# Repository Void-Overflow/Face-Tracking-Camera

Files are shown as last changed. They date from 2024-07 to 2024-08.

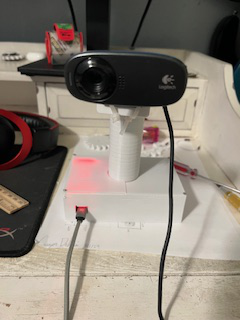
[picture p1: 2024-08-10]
Demo Images and Video/IMG_9484.jpg

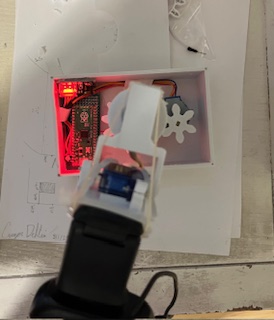
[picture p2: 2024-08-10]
Demo Images and Video/IMG_9477.jpg

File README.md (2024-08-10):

# Face-Tracking-Camera
An RP2040 based mechanical facial tracker with a C++ interface utilizing OpenCV to physically track faces detected in the user's webcam using stepper and servo motors.

Description: 

This project uses the Rasperry Pi Pico microcontroller to run Arduino code which uses UART to communicate with my C++ program. It receives the determined coordinates of a detected face in the webcam with the center of the camera as the origin. It then maps the values from those coordinates to a stepper motor to move it horizontally and a servo to vertically move the camera. The webcam should be mounted on top of the 3d printed base. A slip ring should be used to prevent the wires above the stepper from being tangled. The C++ interface was written in Visual Studio, and it uses OpenCV to detect and track faces from a pretrained haarcascade file. It additionally uses the Windows.h library to communicate with the detected RPi. I have designed my own libraries, SerialCOM and FaceDetect, which respectively open, establish, and interact with a device at a certain serial port, as well as use OpenCV to detect and receive coordinates of a face in the webcam. I addionally created my own function, autoConnect, in the   SerialCOM library which searches all serial ports on the windows computer from COM0-COM30 for a connection message to verify it is the desired device. This message should be sent at all times by the receiver, in this case the RPi Pico.                       

The design of its box consists of a bearing placed on top of the mount in the center with a 3 wire slip ring placed inside of it to assure that it's wires don't get tangled while moving. The wires then go up the tube and connect to the servo motor at the top, in which you can use glue to secure it. Use a method to fasten your webcam to the front of the servo. Personally I found zipties to be effective.

How to Run: 

Since I utilized Windows.h, this project only runs on x64 windows devices. To run this, build the circut according to the schematic in the project. Print my 3d printed design and use a slip ring to prevent the camera and servo from being tangled. See the attached video in this repository to see how it works. This repository doesn't include the OpenCV library as it is too large. To successfully run this program, install OpenCV as well as its extra modules, compile and bulid them using MINGW, go to Software Interface/Face Tracking Camera, create a folder named libs, and put the library in a folder called opencv. Make sure to add the environment variables for opencv as it may not work without it. If it doesn't work, try opening the solution file in Visual Studio and adjuting the library paths, and then rebuild. Once it's set up, run the executable, and it should open up a terminal and after a couple seconds a window from your camera. It should then show you the connection being established with your device on the detected COM port, show a blue square around your face, and the device should then start moving  its servo and stepper motors to center your face within the center of the camera.

Credits: 

This project was all created and designed by Comyar Dehlavi.
OpenCV library was used to detect faces from the webcam, with MINGW being used to compile it.
Visual Studio and Visual Studio code were the development of this as well, with the Arduino extension being used in VS Code to compile for the RPi Pico.

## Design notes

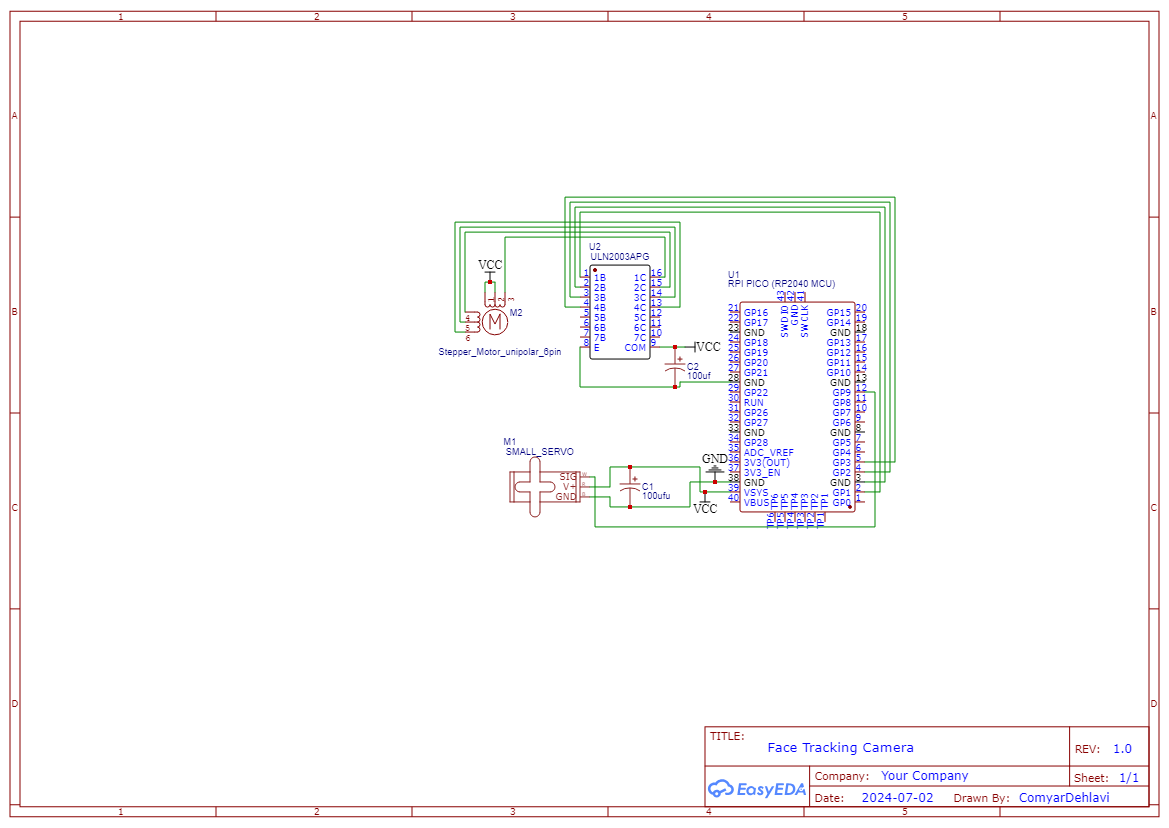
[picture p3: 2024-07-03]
Schematic/Face Tracking Camera_schematic.png

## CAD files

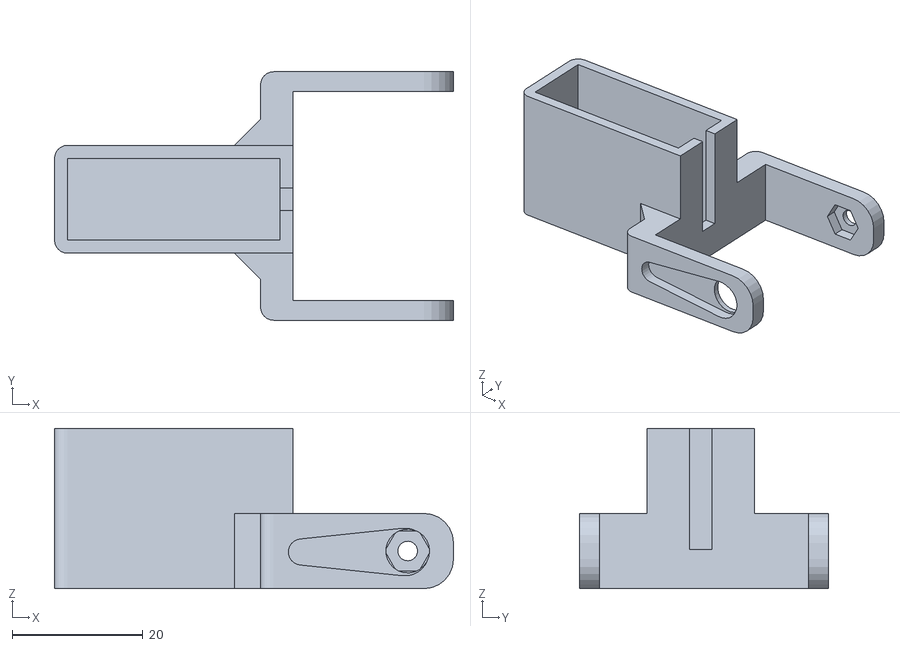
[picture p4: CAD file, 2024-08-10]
3D Printer Files/Servo Tilt Base.stl
61.0 x 38.0 x 24.5

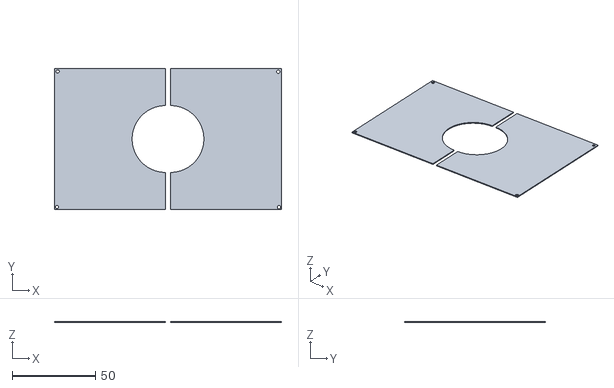
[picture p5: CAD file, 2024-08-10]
3D Printer Files/Box lid.stl
136.3 x 84.9 x 0.556

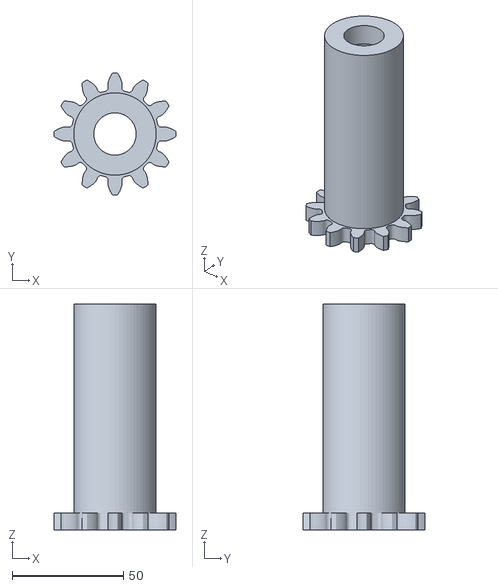
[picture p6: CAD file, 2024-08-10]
3D Printer Files/Bearing Gear-Shaft v8.stl
54.7 x 54.7 x 101.6

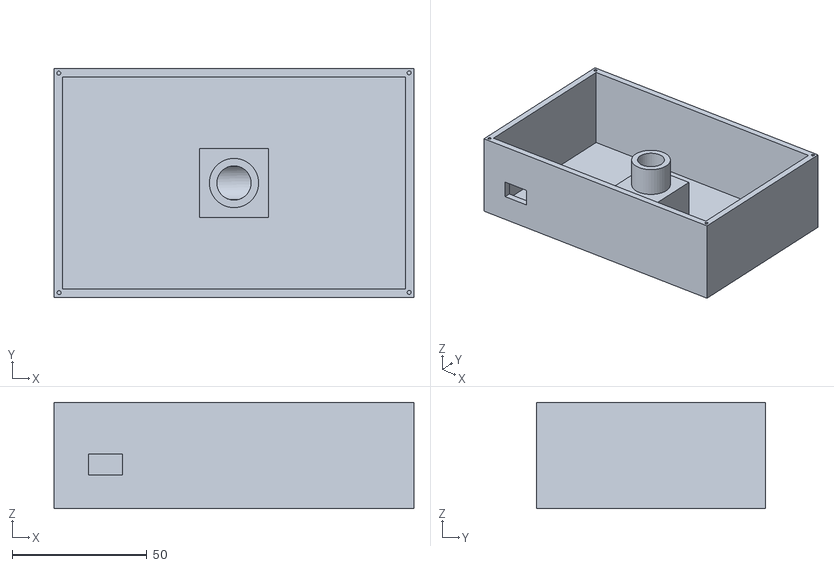
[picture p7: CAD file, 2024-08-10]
3D Printer Files/Box.stl
133.4 x 84.9 x 39.4

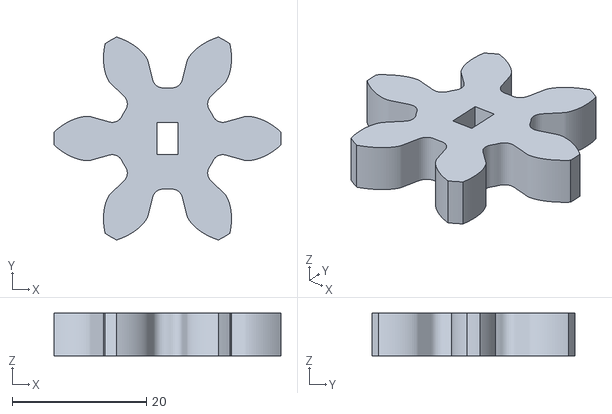
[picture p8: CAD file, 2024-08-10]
3D Printer Files/Motor Gear.stl
33.9 x 30.3 x 6.35

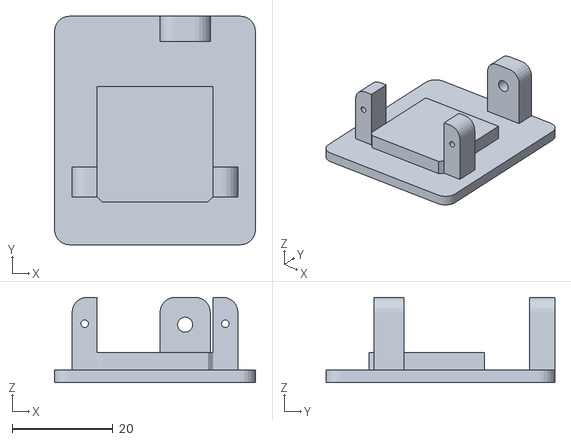
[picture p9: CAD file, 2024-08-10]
3D Printer Files/Servo Tilt.stl
40.0 x 45.5 x 17.0

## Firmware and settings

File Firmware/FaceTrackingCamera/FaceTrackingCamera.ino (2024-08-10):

#include <Stepper.h>

#define servoPin 9
Stepper stepper = Stepper(32, 2, 4, 3, 5); // Pins entered in sequence IN1-IN3-IN2-IN4 for proper step sequence

int NoReceptionElapsed = 0;
int reconnectionAttemptElapsed = 0;
bool isRunning = false;

int x, y;
int servoPos = 90;
bool servoDir = false;

void writeServo(int angle)
{
  // Convert the angle to microseconds (us)
  // Servo range is typically from 1000us (0 degrees) to 2000us (180 degrees)
  int pulseWidth = map(angle, 0, 180, 1000, 2000);

  // Generate the PWM signal
  digitalWrite(servoPin, HIGH);
  delayMicroseconds(pulseWidth);
  digitalWrite(servoPin, LOW);
  delay(25 - pulseWidth / 1000); // Ensure a 20ms period
}

void idle()
{
  if (servoPos >= 180)
    servoDir = true;
  if (servoPos <= 0)
    servoDir = false;

  if (servoDir == false)
  {
    servoPos++;
    stepper.step(2);
  }
  else
  {
    servoPos--;
    stepper.step(-2);
  }

  writeServo(servoPos);
}

void setup()
{
  Serial.begin(115200);
  pinMode(LED_BUILTIN, OUTPUT);
  pinMode(servoPin, OUTPUT);

  stepper.setSpeed(500);

  while (!Serial) // wait for serial port to connect
  {
    idle();
  }
  servoPos = 90;

  delay(250);
  Serial.println("Connected to Face Tracking Camera Receiver!"); // message sent for c++ program to identify RPi
}

void loop()
{
  if (Serial.available())
  {
    String data = Serial.readStringUntil('\n');

    x = data.substring(0, data.indexOf("|")).toInt();
    y = data.substring(data.indexOf("|") + 1).toInt();

    Serial.println("Device Received Coordinates (" + String(x) + "," + String(y) + ")");
    NoReceptionElapsed = millis();
    isRunning = true;
  }
  else if (!Serial.available() && millis() - NoReceptionElapsed >= 2500) // if not connected to device for at least 2.5 seconds
  {
    isRunning = false;
    digitalWrite(LED_BUILTIN, LOW);

    idle();
    if (millis() - reconnectionAttemptElapsed >= 500)
    {
      Serial.println("Connected to Face Tracking Camera Receiver!"); // message sent for c++ program to identify RPi
      reconnectionAttemptElapsed = millis();
    }
  }
  else if (millis() - NoReceptionElapsed < 2500) // if it has been connected in the previous 2.5 seconds
    digitalWrite(LED_BUILTIN, HIGH);

  if (isRunning == true)
  {
    if (x > 40 || x < -40)
      stepper.step((x > 50) ? 2 : -2);

    if (y > 60)
    {
      servoPos++;
      if (servoPos > 180)
        servoPos = 180;
    }
    else if (y < -60)
    {
      servoPos--;
      if (servoPos < 0)
        servoPos = 0;
    }
    writeServo(servoPos);
  }
}

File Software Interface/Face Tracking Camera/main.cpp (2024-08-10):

#include "FaceDetector.h"
#include "SerialCOM.h"

#include <iostream>
#include <windows.h>

std::atomic_int xCoord = 0, yCoord = 0;
std::atomic_bool isRunningSerialThread = false;

void deviceCOM() {
	SerialCOM device;
	while (!device.autoConnect("Connected to Face Tracking Camera Receiver!")) {
		std::this_thread::sleep_for(std::chrono::milliseconds(1000));
	};

	while (isRunningSerialThread) {
		const char* read = device.read();
		if (read == "")
			device.autoConnect("Connected to Face Tracking Camera Receiver!");
		else {
			device.write(std::string(std::to_string(xCoord) + "|" + std::to_string(yCoord) + '\n').c_str());
			std::cout << read << '\n';
		}
	}
	device.close();
}

int main() {
	FaceDetector detect;
	if (!detect.load("libs/opencv/install/etc/haarcascades/haarcascade_frontalface_alt2.xml"))
		return -1;

	std::thread serialCOMThread(deviceCOM);

	while (true) {
		detect.run();
		xCoord = detect.dx;
		yCoord = detect.dy;
		isRunningSerialThread = true;
	}
	isRunningSerialThread = false;
	detect.stop();

	return 0;
}

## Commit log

2024-07-03 Added servo/stepper implementation & created schematic
2024-08-10 Finalized device, box, and documentation
    [Bearing Gear-Shaft v8.stl, Box lid.stl, Box.stl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]
